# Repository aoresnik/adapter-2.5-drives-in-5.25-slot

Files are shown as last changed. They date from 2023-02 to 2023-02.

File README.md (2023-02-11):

# Adapter for multiple 2.5" drives in two 5.25 slots

Published also at Thingiverse: https://www.thingiverse.com/thing:4735207

This is an adapter that allows installing 6 or more (customizable) small 2.5" storage drives into the space of two adjacent 5.25 drive slots. This can be useful with older computer cases that don't have many small drive slots.

Two variants are included:

- Regular variant ([STL file](adapter.stl)): drives can be fitted into the adapter with screws. This is recommended if you want to use this adapter with HDD drives, because these cause vibration and would rattle in the "semi toolless" variant.

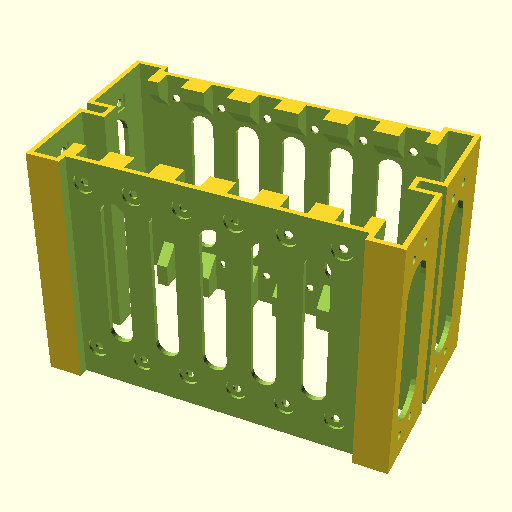
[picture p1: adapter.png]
2.5-in-5.25 adapter rendering
  

- "Semi toolless" variant ([STL file](adapter-semi-toolless.stl)): all drives are secured with a bracket that is kept in place with two M3 screws (that screw into two M3 square nuts that you place in the nut traps). This allows adding and removing drives without removing the adapter from the computer case, if there's enough room to maneuver around it. This is not completely toolless, so I call this variant "semi toolless". Hex screws are recoommended, because there are hex screw drivers available that can work at a slight angle, which can make access easier while the adapter is in the computer case. This version is recommended for SSD drives only.

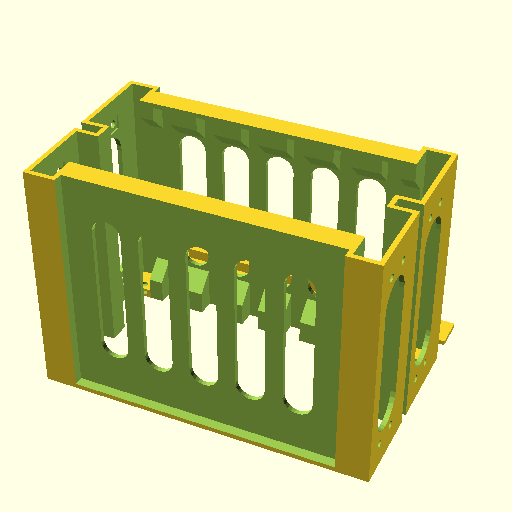
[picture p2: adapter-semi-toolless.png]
Semi-toolless 2.5-in-5.25 adapter rendering
  

Both variants require adding at least 4 square M3 nuts to be carefully glued, centered, into 4 square recesses around the holes at the sides where the adapter gets fitted into the 5.25 slots. Two attachment points at least on each side. Cyanocrilate based glue works for me.

Print in a material with higher temperature resistance, such as PETG or better. I recommend against printing in PLA because it gets soft at 55-60°C. Temperatures inside computer case may reach that levels, causing adapter to deform. Recommended to print with 3 perimeters.

A semi toolless variant as installed in a server case, relieving the shortage of 2.5" slots:

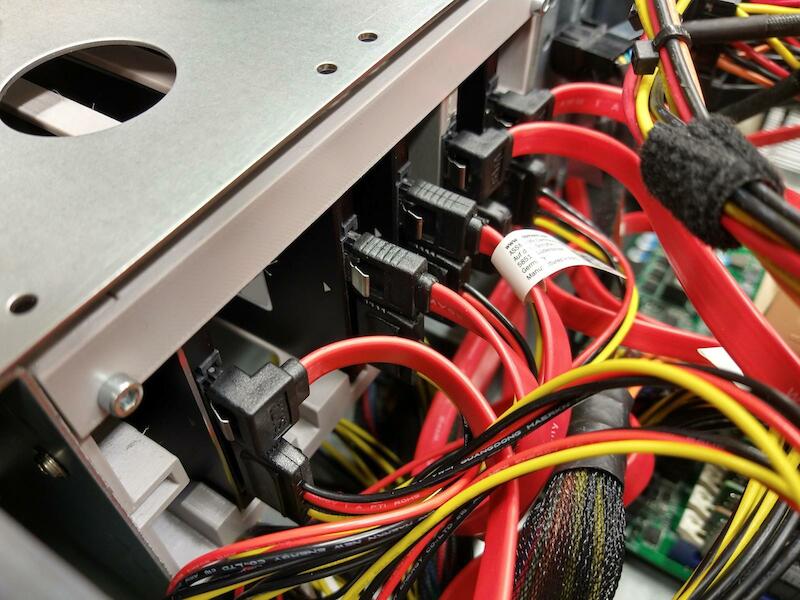
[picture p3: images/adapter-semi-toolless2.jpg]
Semi-toolless 2.5-in-5.25 adapter in use


Shield: [][cc-by]

This work is licensed under a
[Creative Commons Attribution 4.0 International License][cc-by].

[][cc-by]

[cc-by]: http://creativecommons.org/licenses/by/4.0/
[cc-by-image]: https://i.creativecommons.org/l/by/4.0/88x31.png
[cc-by-shield]: https://img.shields.io/badge/License-CC%20BY%204.0-lightgrey.svg

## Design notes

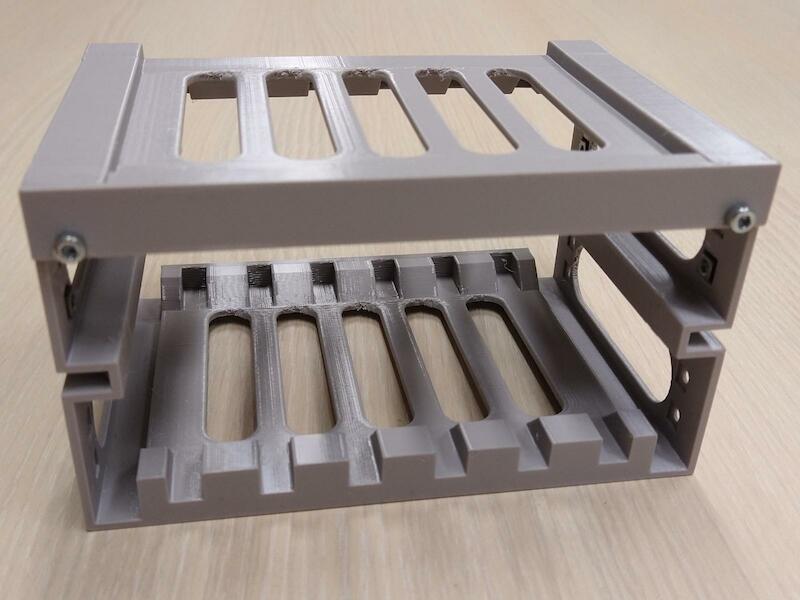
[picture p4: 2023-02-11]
images/adapter-semi-toolless1.jpg

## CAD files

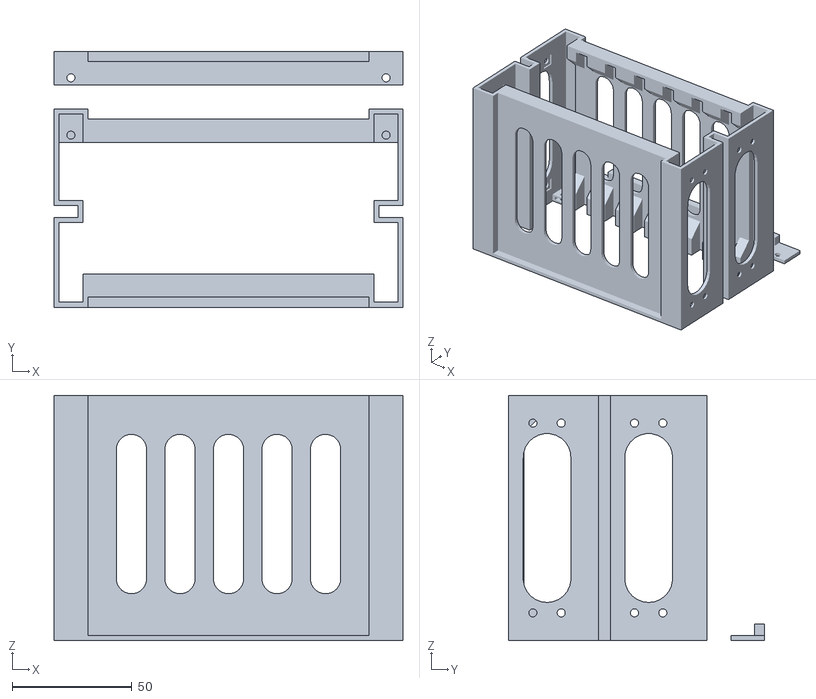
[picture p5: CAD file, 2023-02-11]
adapter-semi-toolless.stl
145.9 x 106.9 x 102.7

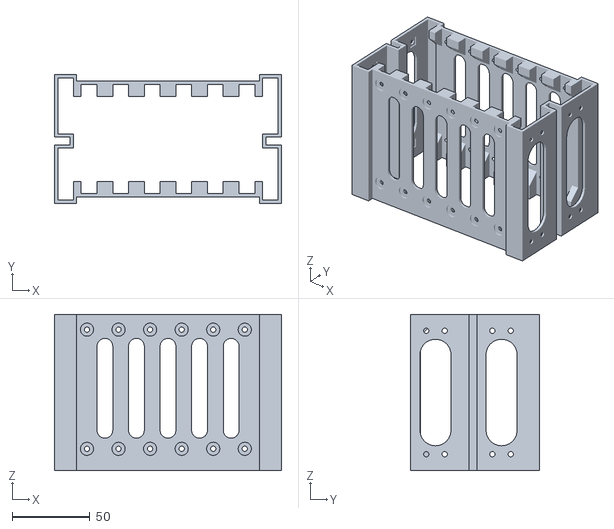
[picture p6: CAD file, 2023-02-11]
adapter.stl
145.9 x 82.9 x 100.5

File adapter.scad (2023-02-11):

// Small distance added to compensate floating point problems when subtracting
// 0.01 is too small, because some remains can be seen in OpenSCAD UI when rotating the object
$epsilon=0.02;
// Default round parts divisions
$fn=25;
// Slack to accomodate printing tolerances (try increasing if unable to fit drives
// or unable to fit the adapter into the slot)
$slack=0.1;

$nut_trap_slack_s=0.5;
$nut_trap_slack_d=0.2;

$layer_thickness=0.2;

SEMI_TOOLLESS=true;

// Source: https://doc.xdevs.com/doc/Seagate/SFF-8201.PDF

// The thickness (height) of the drive. Standard allows many different thicknesses
// Common values are 7.0 for SSD and 9.50 for HDD
sff_8201_A1=7.50;

// max width according to notes (A4+A5)
drive_25_width=70.10 + $slack;
drive_25_height=sff_8201_A1 + $slack;
drive_25_depth=100.45 + $slack;

sff_8201_A52=14 + $slack;
sff_8201_A53=90.60 + $slack;
sff_8201_A23=3.60 + $slack;

// Source: https://doc.xdevs.com/doc/Seagate/SFF-8551.PDF

slot_525_width=146.05 - $slack;
slot_525_height=41.53 - $slack;

sff_8551_A1=41.53 + $slack;
sff_8551_A2=42.30 + 0.2;
sff_8551_A11=79.25 + $slack;
sff_8551_A13=10.00 + $slack;
sff_8551_A14=21.84 + $slack;

square_nut_m3_s=6+$slack;
square_nut_m3_d=1.6;
wall_thickness_square_nut=1.3;

wall_thickness_side=2.1;
wall_thickness_bottom_top=14;
side_space=10;
side_slot_width=5;

adapter_length=SEMI_TOOLLESS ? (drive_25_depth + wall_thickness_side) : drive_25_depth;

n_drives=6;

module bay_attachment_hole()
{
    rotate([0,90,0]) cylinder(r=1.7, h=wall_thickness_side+2*$epsilon);
    translate([wall_thickness_square_nut+$epsilon, -square_nut_m3_s/2-0.1, -square_nut_m3_s/2-0.1]) cube([wall_thickness_side-wall_thickness_square_nut+$epsilon, square_nut_m3_s+0.2, square_nut_m3_s+0.2]);
}

module bay_attachment_holes()
{
    z_offset = (adapter_length-sff_8551_A11)/2;
    
    translate([-$epsilon,sff_8551_A13,z_offset]) bay_attachment_hole();
    translate([-$epsilon,sff_8551_A13,z_offset+sff_8551_A11]) bay_attachment_hole();
    translate([-$epsilon,sff_8551_A14,z_offset]) bay_attachment_hole();
    translate([-$epsilon,sff_8551_A14,z_offset+sff_8551_A11]) bay_attachment_hole();

    // Hole for reduction of material usage    
    translate([-$epsilon,(sff_8551_A14+sff_8551_A13)/2,0])
        hull() {
            translate([0,0,adapter_length-26]) rotate([0,90,0]) cylinder(r=10, h=wall_thickness_side+2*$epsilon);
            translate([0,0,26]) rotate([0,90,0]) cylinder(r=10, h=wall_thickness_side+2*$epsilon);
        };
}

module side_cutouts()
{
    // Left and right spacing
    // Slot moved for $slack upwards
    translate([wall_thickness_side,wall_thickness_side,-$epsilon]) cube([side_space, sff_8551_A2-2*wall_thickness_side-side_slot_width+$slack, adapter_length+2*$epsilon]);

    translate([wall_thickness_side,sff_8551_A2+wall_thickness_side+$slack,-$epsilon]) cube([side_space, 2*slot_525_height-sff_8551_A2-2*wall_thickness_side-$slack, adapter_length+2*$epsilon]);
    
    translate([-$epsilon, sff_8551_A2-side_slot_width+$slack, -$epsilon]) cube([side_space+$epsilon, side_slot_width, adapter_length+2*$epsilon]);
        
    // Holes (reduce material usage)
    //#translate([-$epsilon,(2*slot_525_height)/2,adapter_length/2]) rotate([0,90,0]) cylinder(r=30, h=wall_thickness_side+2*$epsilon, $fn=40);
    
    bay_attachment_holes();
    translate([0,sff_8551_A2,0]) bay_attachment_holes();
}

module drive_attachment_hole()
{
    cylinder(r=1.7, h=wall_thickness_side+2*$epsilon);
    translate([0,0,$epsilon + 1]) cylinder(r=4.25, h=wall_thickness_side + $epsilon - 1);
}

slot_stride = ((slot_525_width-2*wall_thickness_side-2*side_space)/(n_drives));

top_bottom_spacing_x = slot_525_width-2*(side_space+2*wall_thickness_side);
top_bottom_spacing_y = (2*slot_525_height-(drive_25_width+2*wall_thickness_side))/2;

module top_bottom_cutouts(z_cutout_start)
{
    // Top and bottom cutouts
    translate([side_space+2*wall_thickness_side,-$epsilon,z_cutout_start]) cube([top_bottom_spacing_x, top_bottom_spacing_y+$epsilon, adapter_length+2*$epsilon]);

    // Slots for drives
    for ( i = [0 : (n_drives-1)] ){
        translate([wall_thickness_side + side_space + i*slot_stride + slot_stride/2 - drive_25_height/2, ((2*slot_525_height)-drive_25_width)/2, -$epsilon]) {
            // Drive
            cube([drive_25_height, 10, drive_25_depth+2*$epsilon]);
            
            if (!SEMI_TOOLLESS) 
            {
                // Screw holes
                translate([sff_8201_A23,$epsilon,sff_8201_A52]) rotate([90,0,0]) drive_attachment_hole();
                translate([sff_8201_A23,$epsilon,sff_8201_A53]) rotate([90,0,0]) drive_attachment_hole();
            }
        }
    }
    
    // Cutout in fins (reduce material usage)
    // Slot fins should cover the screw hole, because disks have more consistent thickness at this point
    // (important in semi-toolless variant)
    a = wall_thickness_bottom_top-((2*slot_525_height)-drive_25_width)/2;
    #translate([wall_thickness_side+side_space-$epsilon,0,0])
       rotate([90,0,90])         
       linear_extrude(height=slot_525_width-2*wall_thickness_side-2*side_space+2*$epsilon) 
       polygon( points=[
              [wall_thickness_bottom_top+$epsilon,sff_8201_A52-a/2],
              [((2*slot_525_height)-drive_25_width)/2,sff_8201_A52+a/2],
              [((2*slot_525_height)-drive_25_width)/2,sff_8201_A53-a/2],
              [wall_thickness_bottom_top+$epsilon,sff_8201_A53+a/2],
          ]
       );
    
    // Coutouts in top and bottom (reduce material usage)
    hole_r = (slot_stride-drive_25_height)/2;
    for ( i = [1 : (n_drives-1)] ){
        translate([wall_thickness_side + side_space + i*slot_stride + slot_stride/2 - drive_25_height/2, 0, -$epsilon]) {
            hull() {
                translate([-hole_r ,-$epsilon,80]) rotate([-90,0,0]) cylinder(r=hole_r , h=10+2*$epsilon);
                translate([-hole_r ,-$epsilon,20+6]) rotate([-90,0,0]) cylinder(r=hole_r , h=10+2*$epsilon);
            }
        }
    }
}

difference() {
    // Base block
    cube([slot_525_width, 2*slot_525_height, adapter_length]);
    
    // Main internal volume cutout
    translate([wall_thickness_side+side_space-$epsilon,wall_thickness_bottom_top,-$epsilon]) cube([slot_525_width-2*wall_thickness_side-2*side_space+2*$epsilon, 2*slot_525_height-2*wall_thickness_bottom_top, adapter_length+2*$epsilon]);
    
    // Side cutouts (simetrical along the x axis trough the middle plane)
    side_cutouts();
    translate([slot_525_width,0,0]) mirror([1,0,0]) side_cutouts();
    
    // Top and bottom cutouts (simetrical along the y axis trough the middle plane)
    // For semi-toolless variant, add a lip to reduce bending
    top_bottom_cutouts(SEMI_TOOLLESS ? wall_thickness_side : -$epsilon);
    translate([0,2*slot_525_height,0]) mirror([0,1,0]) top_bottom_cutouts(-$epsilon);
}

lock_plate_screw_post_x = side_space;
lock_plate_screw_post_y = wall_thickness_bottom_top-wall_thickness_side;
lock_plate_screw_post_z = square_nut_m3_d + 2*wall_thickness_square_nut;

module lock_plate_screw_post()
{
    translate([wall_thickness_side-$epsilon, 2*slot_525_height-wall_thickness_side-lock_plate_screw_post_y+$epsilon, 0])
        difference () {
            cube([lock_plate_screw_post_x+2*$epsilon, lock_plate_screw_post_y+$epsilon, lock_plate_screw_post_z]);
            translate([(lock_plate_screw_post_x-(square_nut_m3_s+$nut_trap_slack_s))/2, -$epsilon, wall_thickness_square_nut])
                cube([square_nut_m3_s+$nut_trap_slack_s, square_nut_m3_s+$nut_trap_slack_s+$epsilon, square_nut_m3_d+$nut_trap_slack_d]);
            // Hole below square nut trap
            translate([lock_plate_screw_post_x/2, (square_nut_m3_s+$slack)/2, -$epsilon])
              cylinder(r=1.7, h=wall_thickness_square_nut+2*$epsilon);
            // Hole above the square nut trap - leave one layer for support
            translate([lock_plate_screw_post_x/2, (square_nut_m3_s+$slack)/2, wall_thickness_square_nut+square_nut_m3_d+$slack+$layer_thickness])
              cylinder(r=1.7, h=wall_thickness_square_nut);
        }
}

lock_plate_y = wall_thickness_bottom_top;

module lock_plate_screw_hole()
{
    translate([wall_thickness_side+lock_plate_screw_post_x/2, (square_nut_m3_s+$slack)/2, -$epsilon])
        cylinder(r=1.7, h=wall_thickness_side+2*$epsilon);
}

module lock_plate()
{
    difference() {
        cube([slot_525_width, lock_plate_y, wall_thickness_side]);
        lock_plate_screw_hole();
        translate([slot_525_width,0,0]) mirror([1,0,0]) lock_plate_screw_hole();
    }
    
    translate([(slot_525_width-(top_bottom_spacing_x-2*$slack))/2, lock_plate_y-top_bottom_spacing_y+$slack, wall_thickness_side])
        cube([top_bottom_spacing_x-2*$slack, top_bottom_spacing_y-$slack, 5]);
}
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

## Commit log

2020-03-08 Reduce material usage
    [adapter.scad]
2020-03-08 A bit more cutouts
    [adapter.scad]
2020-03-09 Parametrized and corrected M3 square nut dimensions
    [adapter.scad]
2020-03-10 Documented sources and named dimensions according to standard
    [adapter.scad]
2020-03-10 Makefile to build STL from OpenSCAD file
2020-03-10 Fixed alignment of slots
    [adapter.scad]
2020-03-10 Option to add slack to compensate for printing inaccuracies
    [adapter.scad]
2020-03-11 Recesses for screws for drives
    [adapter.scad]
2020-03-16 Simplified (left and right symetrical sides only once)
    [adapter.scad]
2020-03-16 Slot at the side where most of 5.25" spaces have a small "ledge"
    [adapter.scad]
2020-03-21 Thinner walls
    [adapter.scad]
2020-03-21 Semi-toolless option
    [adapter.scad]
2020-03-21 Reinforced the lock plate
    [adapter.scad]
2020-03-21 Simplified the cutouts that are simetrical wrt. top and bottom
    [adapter.scad]
2020-03-21 More of the slot fins kept
    [adapter.scad]
2020-03-24 Semi-tooless variant fixed printability of screw holes and added a lip to reduce bottom edge bending
    [adapter.scad]
2020-03-24 A bit wider lock plate
    [adapter.scad]
2021-01-24 Many changes to make it more sturdy: if you push a drive, it doesn't slip at the other end
    [adapter.scad]
2023-02-11 Small fixes and comments about Makefile
    [adapter.scad]
2023-02-11 Added rendered images and STL files
    [adapter-semi-toolless.stl, adapter.stl]
2023-02-11 Added links to STL files

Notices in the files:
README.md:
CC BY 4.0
